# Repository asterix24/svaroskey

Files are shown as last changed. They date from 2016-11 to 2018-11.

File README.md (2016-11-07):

# svaroskey
The real and original opensource keyboard!

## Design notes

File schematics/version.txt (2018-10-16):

[petroskey]
name = "Petroskey Keyboard"
hw_ver = "0"
pcb_ver = "A"
date = "27/10/2016"

[controller]
name = "Keyboard Controller"
hw_ver = "0"
pcb_ver = "A"
date = "27/10/2016"

[controller-light]
name = "Keyboard Controller light"
hw_ver = "0"
pcb_ver = "A"
date = "04/10/2018"

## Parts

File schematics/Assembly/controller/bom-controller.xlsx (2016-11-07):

Bill of Materials
Date: Thursday, 27 October 2016 17:27:05
Project: "Keyboard Controller"
Hardware_version: "0"
PCB_version: "A"
BOM files:
- bom-controller.xls
NP=NON MONTARE!
Statistics:
52 | C Capacitors
3 | D Diodes
5 | J Connectors
9 | L Inductors, chokes
12 | Q Transistors
1 | S Mechanical parts and buttons
76 | R Resistors
9 | U IC
1 | Y Cristal, quarz, oscillator
168 | Total
T.Qty | bom-controller.xls | Designator | Comment | Footprint | Description
J Connectors
1 | 1 | J1 | Connector | usb_typeB_mini_smd | Mini USB SMT Type B 5 Contacts
1 | 1 | J3 | Connector | fcc-zif_10pin_0.5mm | Header, 10-Pin
1 | 1 | J5 | Connector | HEADER_1X3_2.54MM_THD | Header, 3-Pin
1 | 1 | J2 | Connector | HEADER_1X4_2.54MM_THD | Header, 4-Pin
1 | 1 | J4 | Connector | usb_typeB_mini_smd | Mini USB SMT Type B 5 Contacts (WE 65100516121)
S Mechanical parts and buttons
1 | 1 | BUZ1 | BUZZER | buzzer_14mm_thd
R Resistors
38 | 38 | R4, R6, R7, R10, R11, R12, R13, R14, R17, R18, R19, R20, R21, R22, R23, R24, R25, R26, R27, R28, R29, R30, R31, R32, R33, R34, R35, R36, R37, R38, R39, R40, R49, R50, R51, R52, R53, R54 | 33R | 0603_[1608] | Resistor
1 | 1 | R16 | 180R | 0603_[1608] | Resistor
1 | 1 | R15 | 680R | 0603_[1608] | Resistor
11 | 11 | R43, R47, R56, R58, R60, R62, R64, R66, R68, R70, R72 | 1k | 0603_[1608] | Resistor
1 | 1 | R45 | 1k5 | 0603_[1608] | Resistor
2 | 2 | R75, R76 | 3k3 | 0805_[2012] | Resistor
9 | 9 | R55, R57, R59, R61, R63, R65, R67, R69, R71 | 4k7 | 0603_[1608] | Resistor
5 | 5 | R2, R3, R5, R8, R9 | 10k | 0603_[1608] | Resistor
3 | 3 | R41, R73, R74 | 10k | 0603_[1608] | Resistor
1 | 1 | R44 | 33k | 0603_[1608] | Resistor
2 | 2 | R42, R48 | 47k | 0603_[1608] | Resistor
1 | 1 | R46 | 100k | 0603_[1608] | Resistor
1 | 1 | R1 | 1M | 0603_[1608] | Resistor
C Capacitors
2 | 2 | C1, C3 | 27pF | 0603_[1608] | Ceramic NP0 +/- 0.1
2 | 2 | C42, C45 | 10nF | 0603_[1608] | Ceramic X7R 50V
1 | 1 | C50 | 100nF | 0603_[1608] | CER 50V X7R
39 | 39 | C2, C7, C8, C9, C10, C13, C15, C16, C17, C18, C19, C20, C21, C22, C23, C24, C25, C26, C27, C28, C29, C30, C31, C32, C33, C34, C35, C36, C37, C38, C39, C41, C43, C46, C47, C48, C49, C51, C52 | 100nF | 0603_[1608] | Ceramic X7R 50V
1 | 1 | C4 | 1uF | 0603_[1608] | Ceramic X7R 16V
2 | 2 | C5, C6 | 2.2uF | 0603_[1608] | Ceramic 6.3V X7R
1 | 1 | C11 | 4.7uF | 0603_[1608] | Ceramic X7R 16V
1 | 1 | C40 | 4.7uF | 1206_[3216] | Ceramic X7R 16V
1 | 1 | C44 | 4.7uF | 1206_[3216] | Ceramic X5R 25V
2 | 2 | C12, C14 | 10uF | 1206_[3216] | Ceramic X5R 25V
D Diodes
2 | 2 | D1, D2 | LED | 0603_[1608]_K2-A1_LED | LED Green
1 | 1 | D3 | MBR120VLSFT1G | SOD-123 | Diode Schottky low Vf, If 1A (PMEG3010ER; MBRX120LF)
L Inductors, chokes
8 | 8 | L2, L3, L4, L5, L6, L7, L8, L9 | 220H ohm @ 100MHz | 0805_[2012] | WE 742792022
1 | 1 | L1 | 220H ohm @ 100MHz | 0805_[2012] | Inductor
Q Transistors
3 | 3 | Q1, Q2, Q3 | BC817 | SOT-23 | BJT NPN
1 | 1 | Q4 | MOSFET P | SOT-23 | IRLML5103TRPbF; DMG1013UW;
8 | 8 | Q5, Q6, Q7, Q8, Q9, Q10, Q11, Q12 | MOSFET P | SOT-23
Y Cristal, quarz, oscillator
1 | 1 | Y1 | 8MHz | CRYSTAL_3.2X2.5MM_4P_SMD
U IC
1 | 1 | U1 | 24C128 | SOIC8 | EEPROM
1 | 1 | U6 | FT232RQ | QFN-32 | Serial TTL 232 <-> USB (QFN-32)
1 | 1 | U3 | LM1117xxx-3.3 | SOT-223 | LM1117 LDO Fixed output
2 | 2 | U8, U9 | Led Driver | TSOP65P640X120_HS-25N | (Texas TLC5928; ST STP16CP05)
1 | 1 | U7 | MC74HC595AD | SOIC16 | 8-Bit Serial-Input/Serial or Prallel-Output Shift Register with Latched 3-State Outputs
1 | 1 | U2 | STM32F103RB | TSQFP50P1200X1200X160-64N | STM32F103RB
2 | 2 | U4, U5 | TVS Array (WE 82400152) | SOT-563 | TVS Array (WE 82400152)

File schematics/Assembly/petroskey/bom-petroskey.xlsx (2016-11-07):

Bill of Materials
Date: Thursday, 27 October 2016 17:27:05
Project: "Petroskey Keyboard"
Hardware_version: "0"
PCB_version: "A"
BOM files:
- bom-petroskey.xls
NP=NON MONTARE!
Statistics:
52 | C Capacitors
139 | D Diodes
4 | J Connectors
9 | L Inductors, chokes
12 | Q Transistors
66 | S Mechanical parts and buttons
76 | R Resistors
9 | U IC
1 | Y Cristal, quarz, oscillator
368 | Total
T.Qty | bom-petroskey.xls | Designator | Comment | Footprint | Description
J Connectors
1 | 1 | J5 | Connector | fcc-zif_10pin_0.5mm
1 | 1 | J3 | Connector | usb_typeB_mini_smd | Mini USB SMT Type B 5 Contacts (WE 65100516121)
1 | 1 | J4 | Connector | HEADER_1X6_2.54MM_THD | Pin Header, 1x6, 2.54mm.
1 | 1 | J1 | Connector | usb_typeB_mini_smd | Mini USB SMT Type B 5 Contacts
S Mechanical parts and buttons
1 | 1 | BUZ1 | BUZZER | buzzer_14mm_thd
65 | 65 | K1, K2, K3, K4, K5, K6, K7, K8, K9, K10, K11, K12, K13, K14, K15, K16, K17, K18, K19, K20, K21, K22, K23, K24, K25, K26, K27, K28, K29, K30, K31, K32, K33, K34, K35, K36, K37, K38, K39, K40, K41, K42, K43, K44, K45, K46, K47, K48, K49, K50, K51, K52, K53, K54, K55, K56, K57, K58, K59, K60, K61, K62, K63, K64, K65 | KEY0 | tactile_switch_gateron_pcb | Tactile Switch Right Angle 6x6
R Resistors
40 | 40 | R12, R13, R16, R17, R18, R19, R20, R21, R25, R27, R30, R31, R32, R33, R36, R37, R38, R39, R40, R41, R42, R43, R44, R45, R46, R47, R48, R49, R50, R51, R52, R53, R54, R55, R56, R57, R58, R59, R76, R77 | 33R | 0603_[1608] | Resistor
1 | 1 | R35 | 180R | 0603_[1608] | Resistor
1 | 1 | R34 | 680R | 0603_[1608] | Resistor
11 | 11 | R5, R61, R63, R65, R67, R69, R71, R73, R75, R80, R82 | 1k | 0603_[1608] | Resistor
1 | 1 | R7 | 1k5 | 0603_[1608] | Resistor
2 | 2 | R78, R79 | 3k3 | 0805_[2012] | Resistor
9 | 9 | R60, R62, R64, R66, R68, R70, R72, R74, R83 | 4k7 | 0603_[1608] | Resistor
5 | 5 | R23, R24, R26, R28, R29 | 10k | 0603_[1608] | Resistor
1 | 1 | R1 | 10k | 0603_[1608] | Resistor
1 | 1 | R6 | 33k | 0603_[1608] | Resistor
2 | 2 | R2, R81 | 47k | 0603_[1608] | Resistor
1 | 1 | R8 | 100k | 0603_[1608] | Resistor
1 | 1 | R22 | 1M | 0603_[1608] | Resistor
C Capacitors
2 | 2 | C11, C13 | 27pF | 0603_[1608] | Ceramic NP0 +/- 0.1
2 | 2 | C3, C7 | 10nF | 0603_[1608] | Ceramic X7R 50V
1 | 1 | C50 | 100nF | 0603_[1608] | CER 50V X7R
39 | 39 | C2, C4, C5, C8, C9, C10, C12, C17, C18, C19, C20, C23, C25, C26, C27, C28, C29, C30, C31, C32, C33, C34, C35, C36, C37, C38, C39, C40, C41, C42, C43, C44, C45, C46, C47, C48, C49, C51, C52 | 100nF | 0603_[1608] | Ceramic X7R 50V
1 | 1 | C14 | 1uF | 0603_[1608] | Ceramic X7R 16V
2 | 2 | C15, C16 | 2.2uF | 0603_[1608] | Ceramic 6.3V X7R
1 | 1 | C21 | 4.7uF | 0603_[1608] | Ceramic X7R 16V
1 | 1 | C1 | 4.7uF | 1206_[3216] | Ceramic X7R 16V
1 | 1 | C6 | 4.7uF | 1206_[3216] | Ceramic X5R 25V
2 | 2 | C22, C24 | 10uF | 1206_[3216] | Ceramic X5R 25V
D Diodes
35 | 35 | D156, D157, D158, D159, D165, D166, D167, D168, D173, D174, D175, D176, D181, D182, D183, D184, D189, D190, D191, D192, D197, D198, D199, D201, D206, D207, D208, D209, D212, D213, D214, D215, D216, D217, D218 | LED | R3_RGB_LED_THD | Led RGB Thrue Hole
2 | 2 | D2, D3 | LED | 0603_[1608]_K2-A1_LED | LED Green
1 | 1 | D1 | MBR120VLSFT1G | SOD-123 | Diode Schottky low Vf, If 1A (PMEG3010ER; MBRX120LF)
30 | 30 | D148, D152, D154, D155, D160, D161, D162, D163, D169, D170, D171, D172, D177, D178, D179, D180, D185, D186, D187, D188, D193, D194, D195, D196, D202, D203, D204, D205, D210, D211 | RBG |  | Led RGB Thrue Hole
6 | 6 | D149, D150, D151, D153, D164, D200 | RBG | led_3.2x2.8mm_4p_smd | Led RGB Thrue Hole
65 | 65 | D4, D5, D6, D7, D8, D9, D10, D11, D12, D13, D14, D15, D16, D17, D18, D19, D20, D21, D22, D23, D24, D25, D26, D27, D28, D29, D30, D31, D32, D33, D34, D35, D36, D37, D38, D39, D40, D41, D42, D43, D44, D45, D46, D47, D48, D49, D50, D51, D52, D53, D54, D55, D56, D57, D58, D59, D60, D61, D62, D63, D64, D65, D66, D67, D68 | diode | SOD-123 | Diode Schottky low Vf, If 1A (PMEG3010ER; MBRX120LF)
L Inductors, chokes
8 | 8 | L1, L2, L3, L4, L5, L6, L7, L9 | 220H ohm @ 100MHz | 0805_[2012] | WE 742792022
1 | 1 | L8 | 220H ohm @ 100MHz | 0805_[2012] | Inductor
Q Transistors
3 | 3 | Q1, Q2, Q11 | BC817 | SOT-23 | BJT NPN
1 | 1 | Q3 | MOSFET P | SOT-23 | IRLML5103TRPbF; DMG1013UW;
8 | 8 | Q4, Q5, Q6, Q7, Q8, Q9, Q10, Q12 | MOSFET P | SOT-23
Y Cristal, quarz, oscillator
1 | 1 | Y1 | 8MHz | CRYSTAL_3.2X2.5MM_4P_SMD
U IC
1 | 1 | U4 | 24C128 | SOIC8 | EEPROM
1 | 1 | U3 | FT232RQ | QFN-32 | Serial TTL 232 <-> USB (QFN-32)
1 | 1 | U6 | LM1117xxx-3.3 | SOT-223 | LM1117 LDO Fixed output
2 | 2 | U8, U9 | Led Driver | TSOP65P640X120_HS-25N | (Texas TLC5928; ST STP16CP05)
1 | 1 | U7 | MC74HC595AD | SOIC16 | 8-Bit Serial-Input/Serial or Prallel-Output Shift Register with Latched 3-State Outputs
1 | 1 | U5 | STM32F103RB | TSQFP50P1200X1200X160-64N | STM32F103RB
2 | 2 | U1, U2 | TVS Array (WE 82400152) | SOT-563 | TVS Array (WE 82400152)

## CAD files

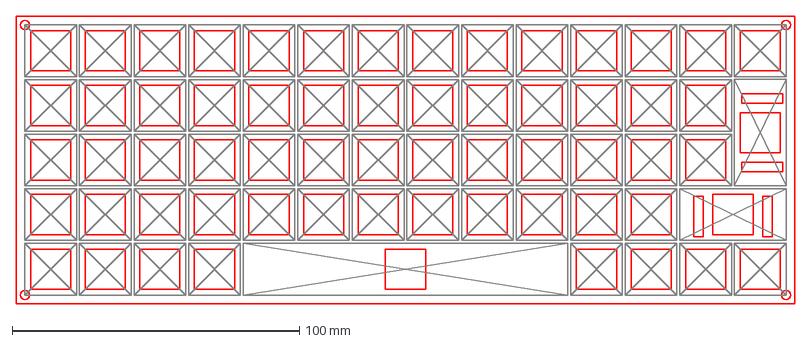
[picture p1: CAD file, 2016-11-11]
schematics/Drawing/pietroskey_layout.dxf
271.0 x 100.0 mm

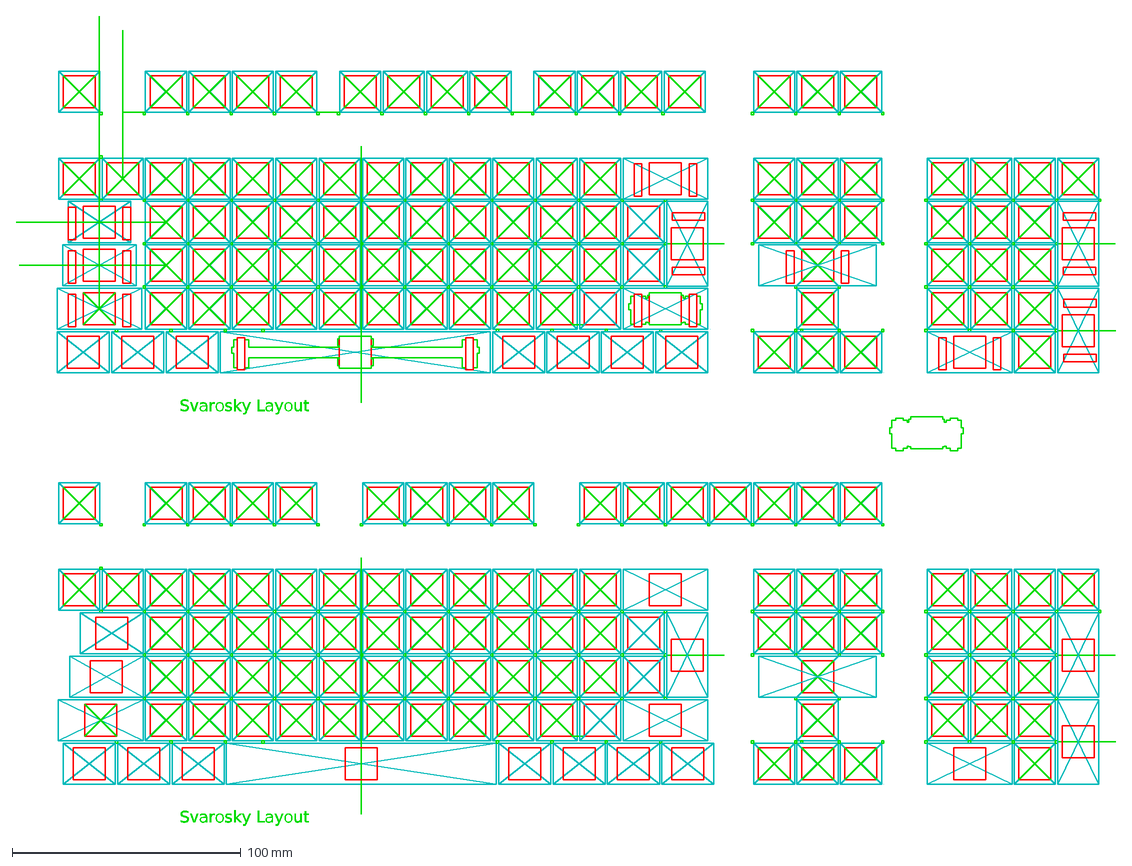
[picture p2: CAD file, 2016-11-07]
schematics/Drawing/svarosky_layout.dxf
Svarosky Layout

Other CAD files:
schematics/Drawing/asterix-print.dxf
schematics/Drawing/asterix_layout_variante.dxf
schematics/Drawing/asterix_layout.dxf
schematics/Drawing/disegno_tastiera.dxf
schematics/Drawing/asterix_layout_variante.dwg

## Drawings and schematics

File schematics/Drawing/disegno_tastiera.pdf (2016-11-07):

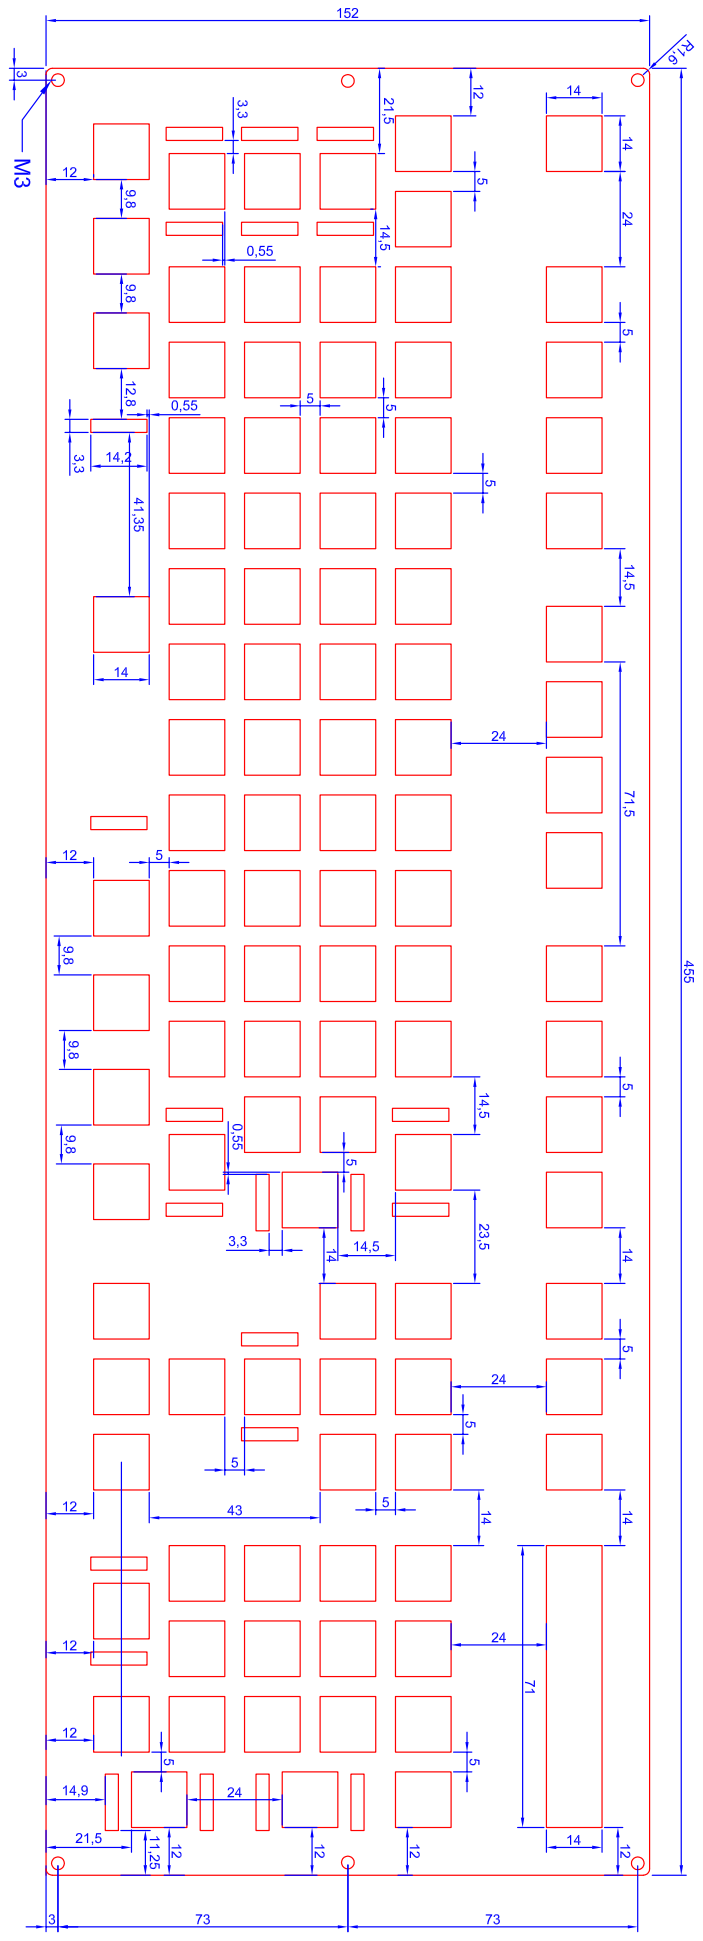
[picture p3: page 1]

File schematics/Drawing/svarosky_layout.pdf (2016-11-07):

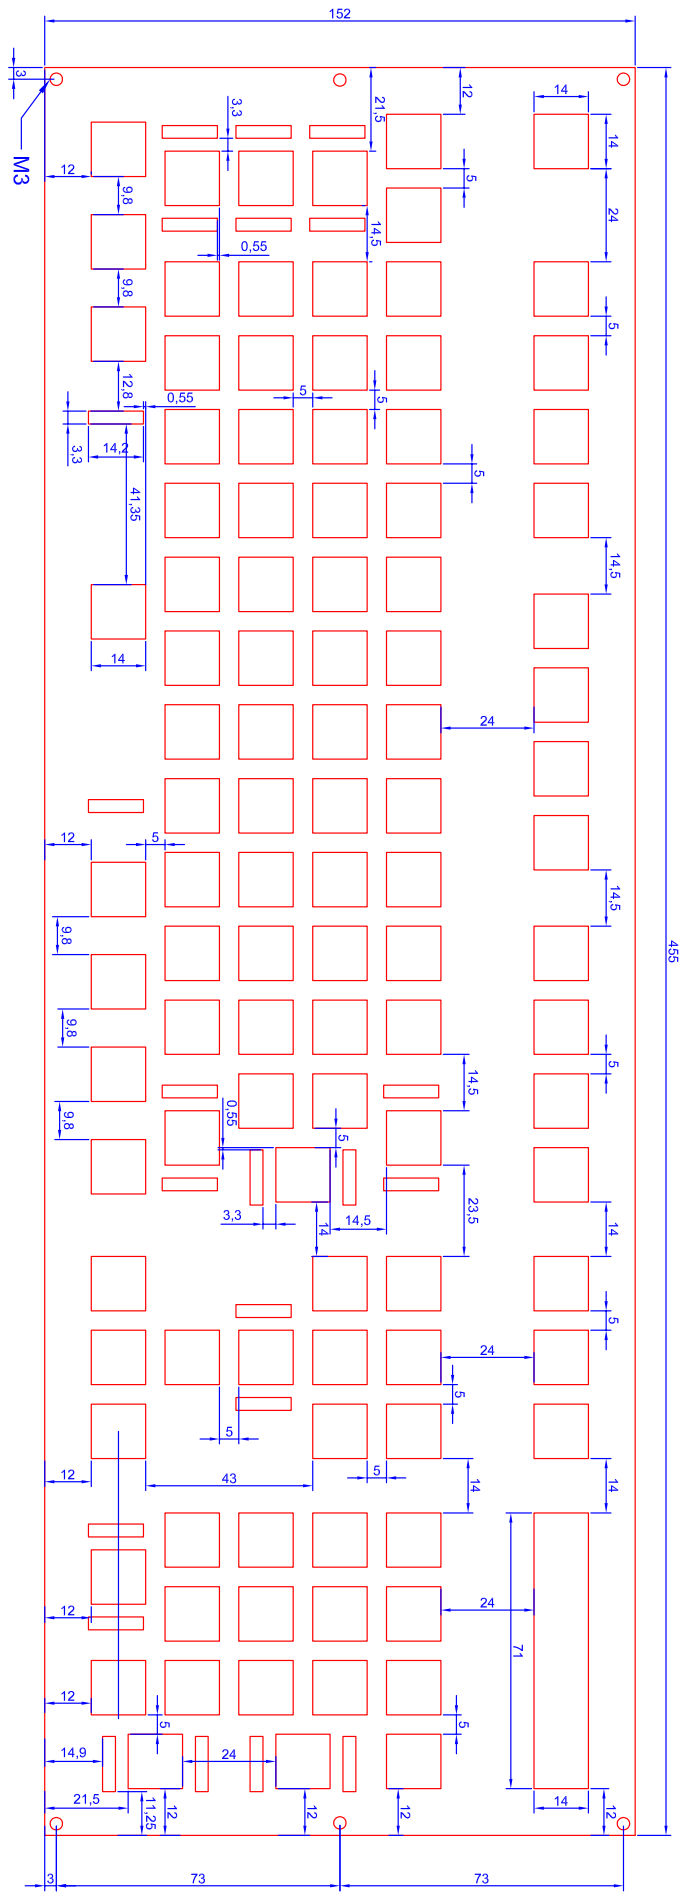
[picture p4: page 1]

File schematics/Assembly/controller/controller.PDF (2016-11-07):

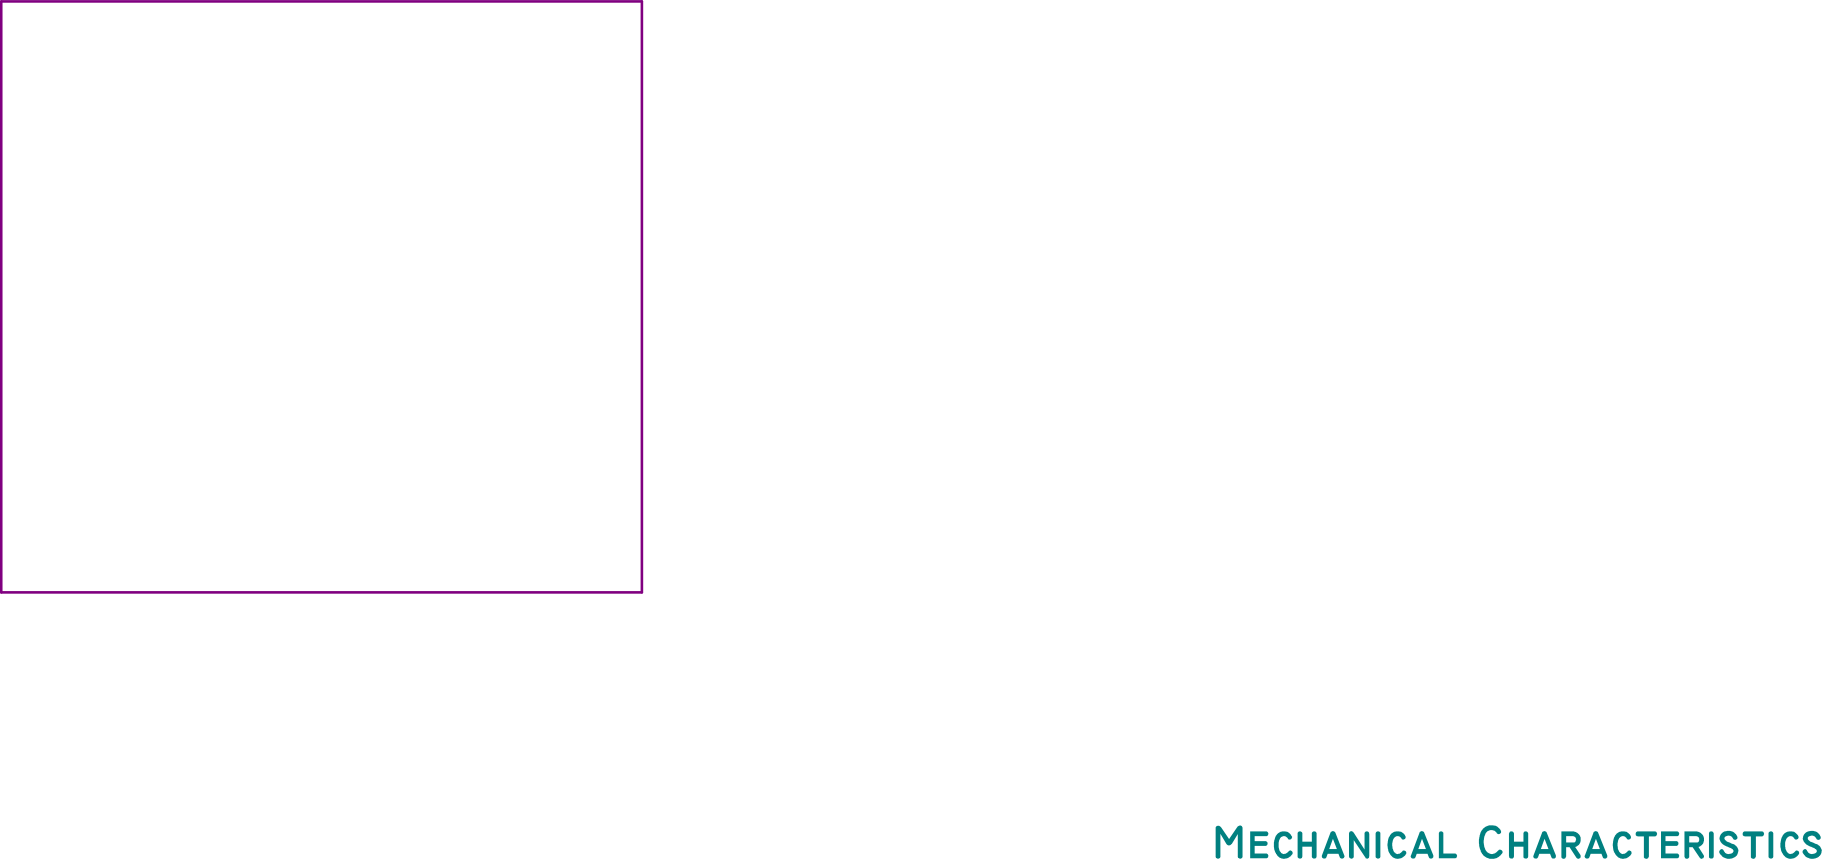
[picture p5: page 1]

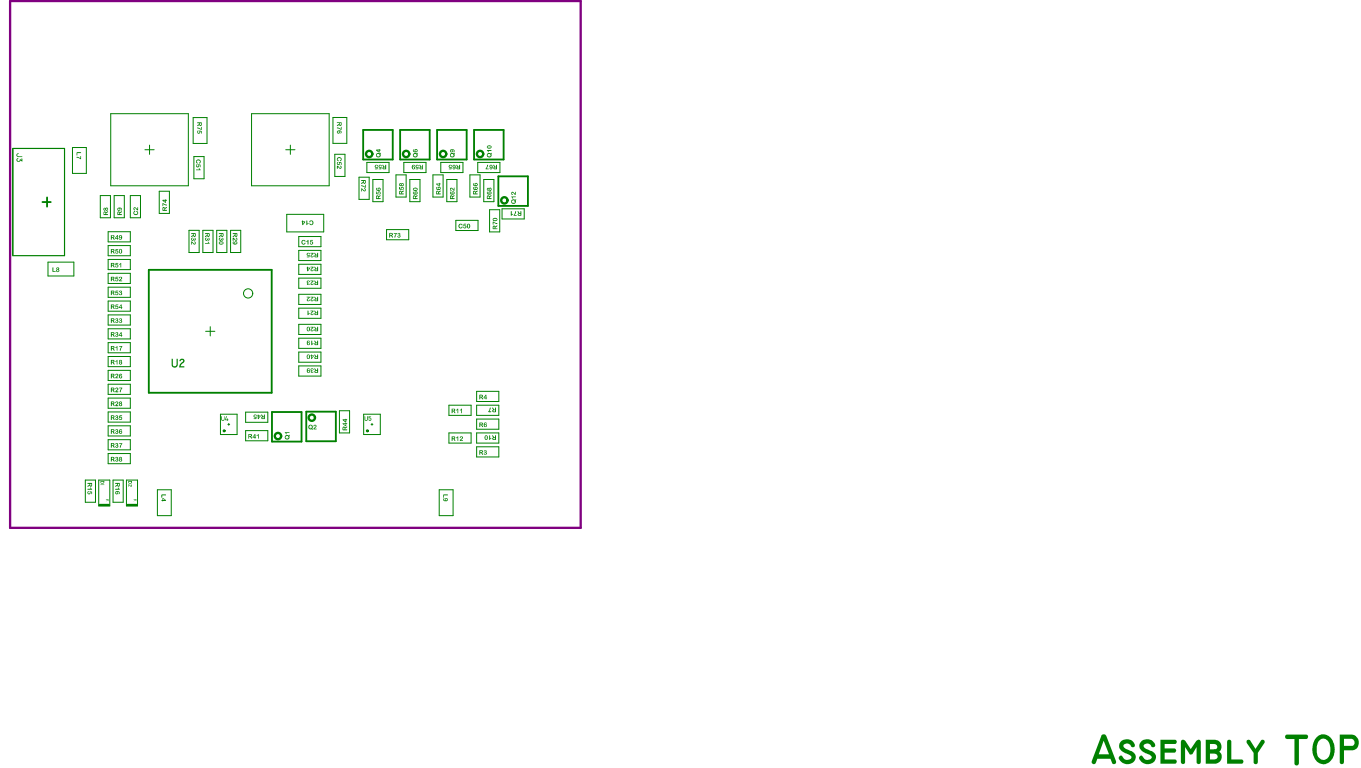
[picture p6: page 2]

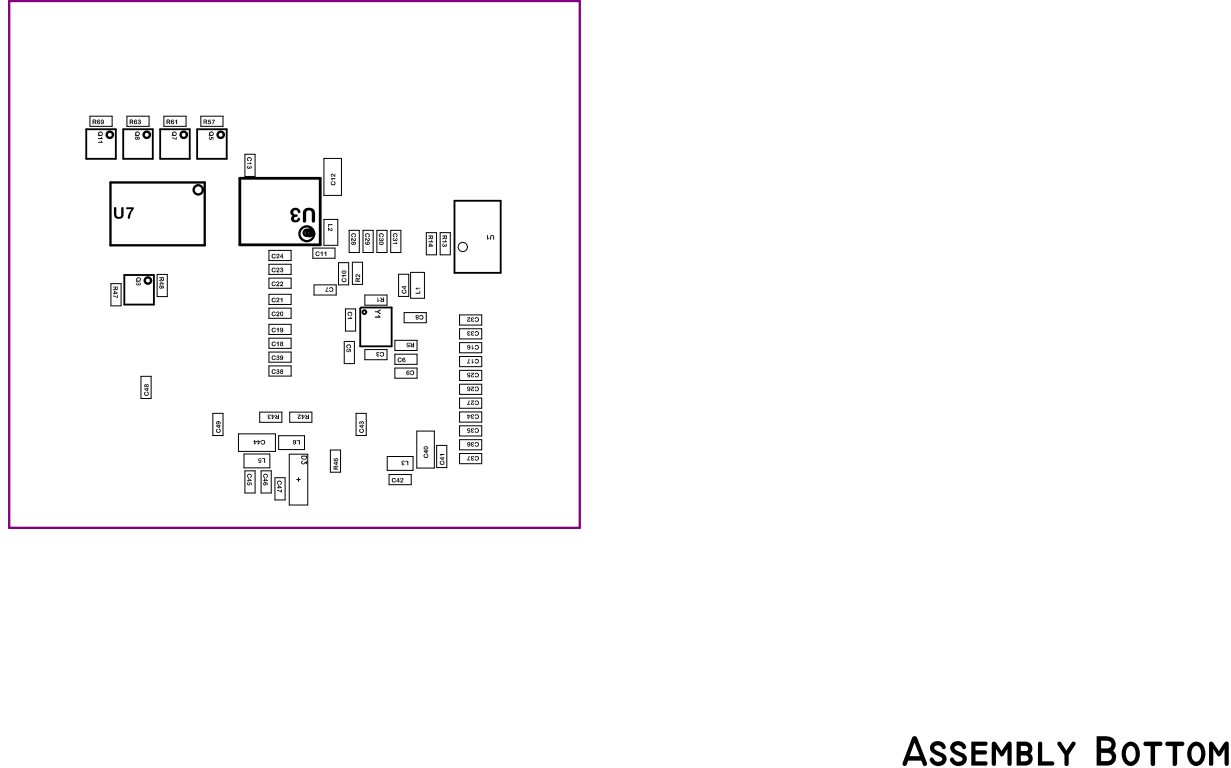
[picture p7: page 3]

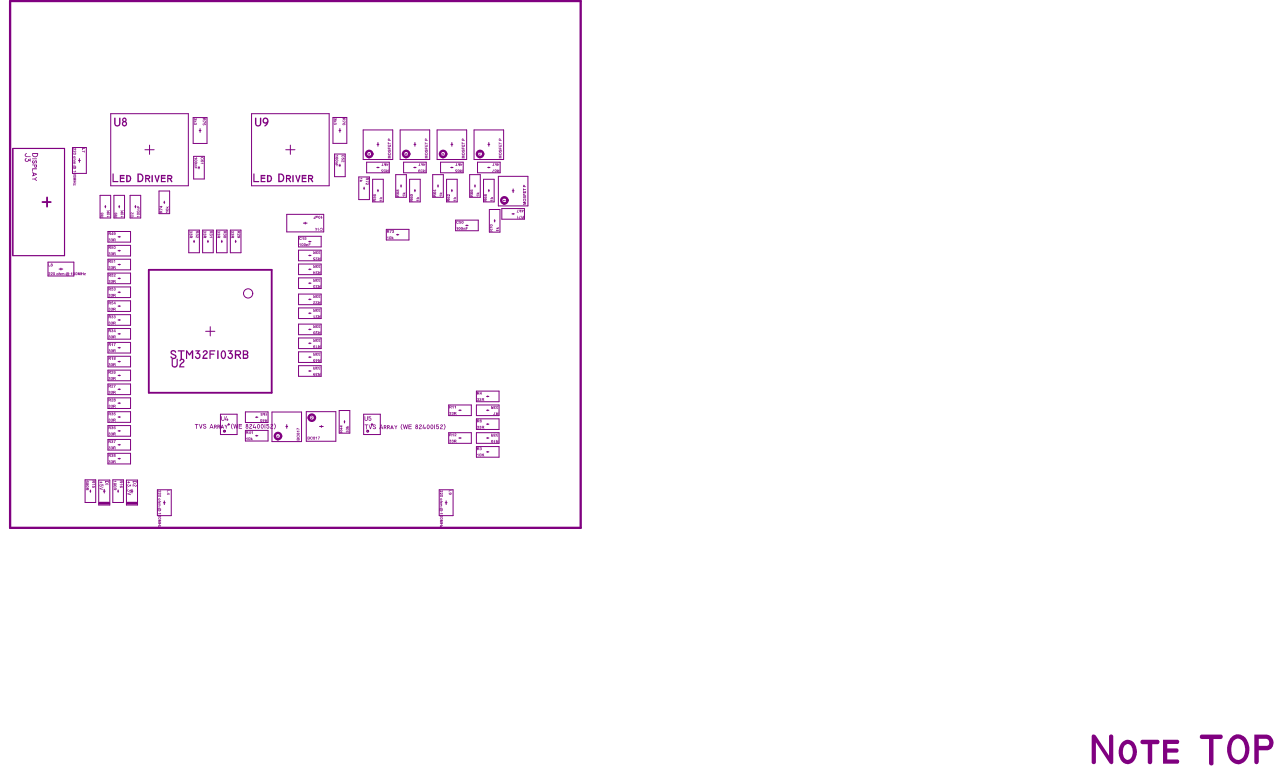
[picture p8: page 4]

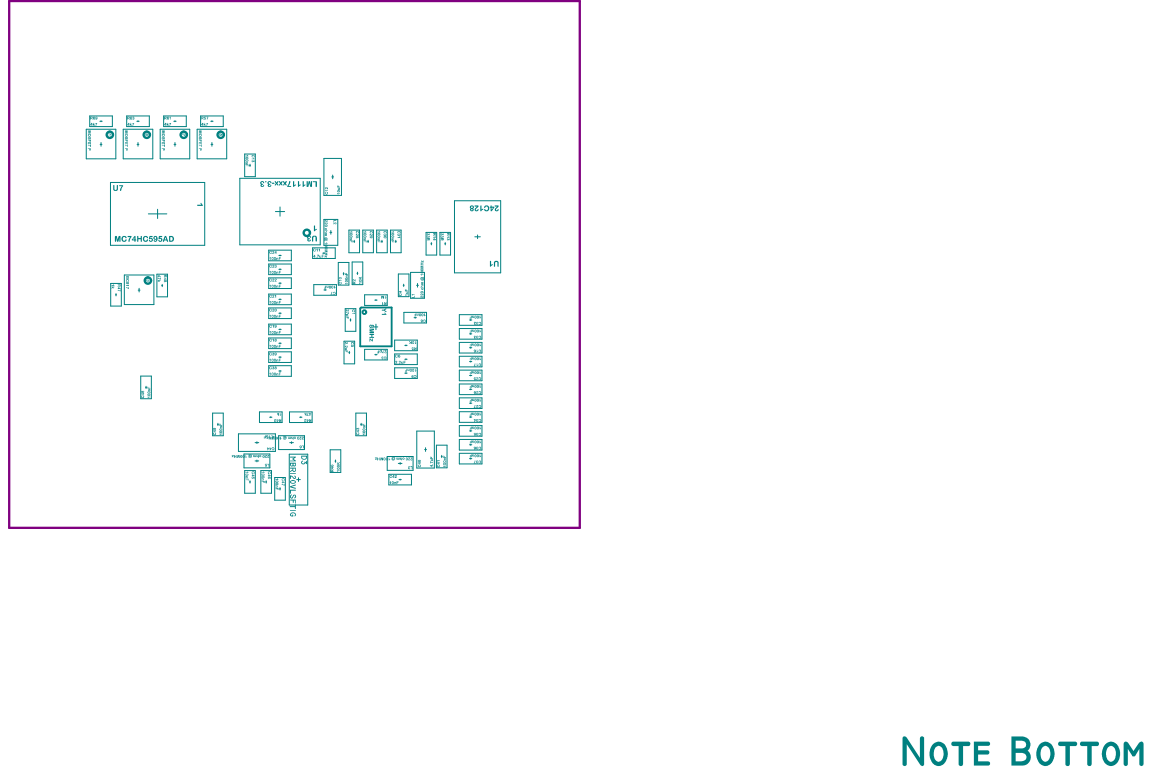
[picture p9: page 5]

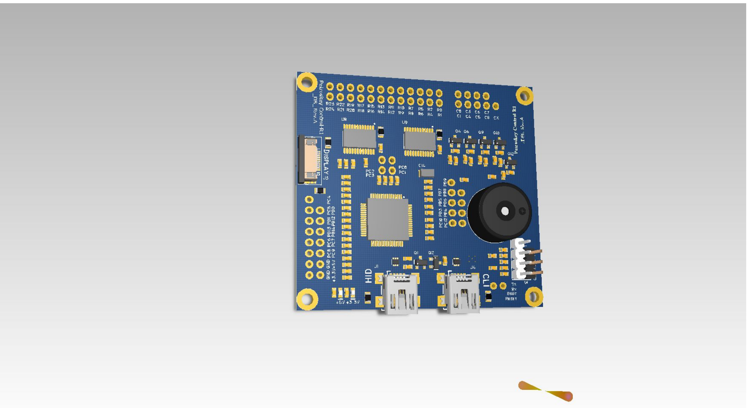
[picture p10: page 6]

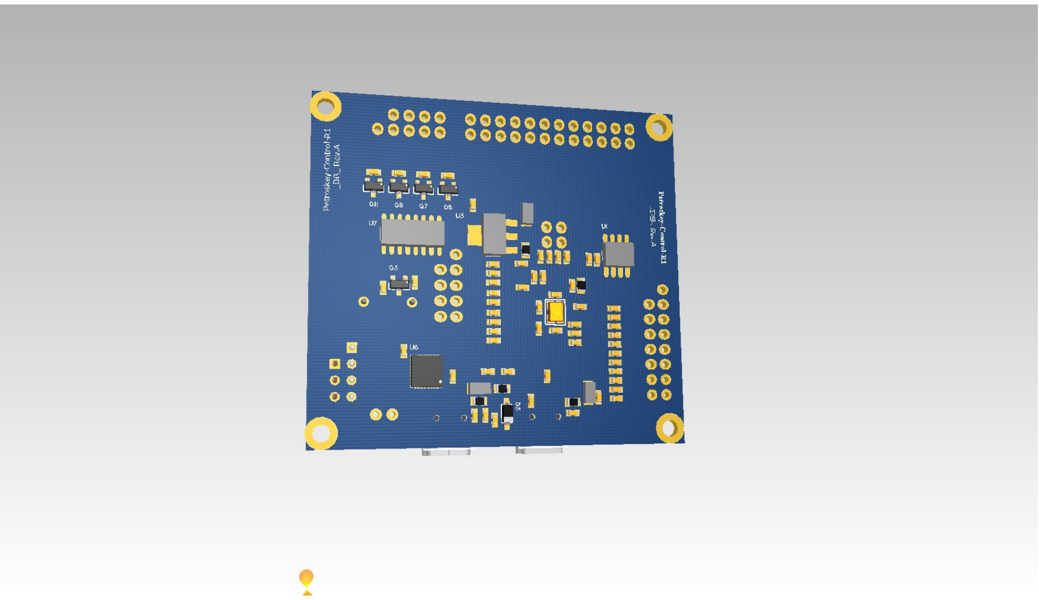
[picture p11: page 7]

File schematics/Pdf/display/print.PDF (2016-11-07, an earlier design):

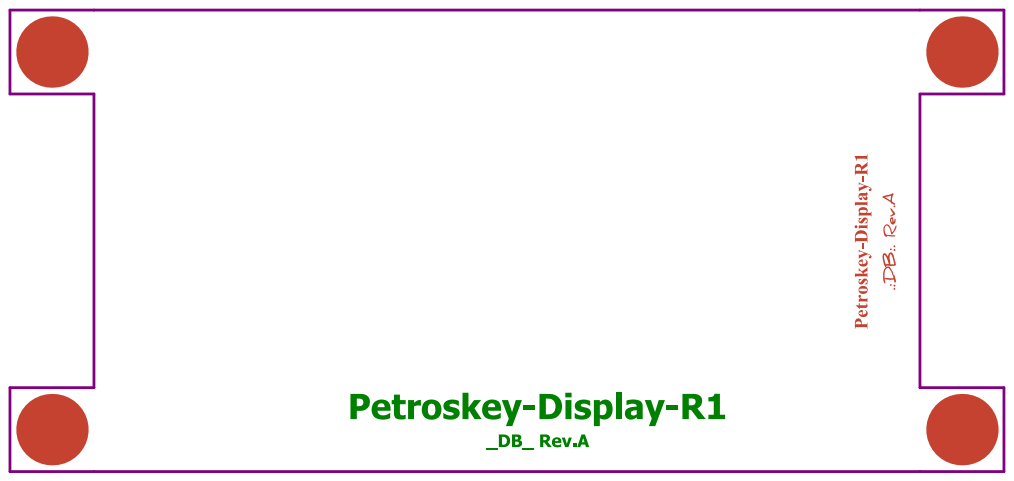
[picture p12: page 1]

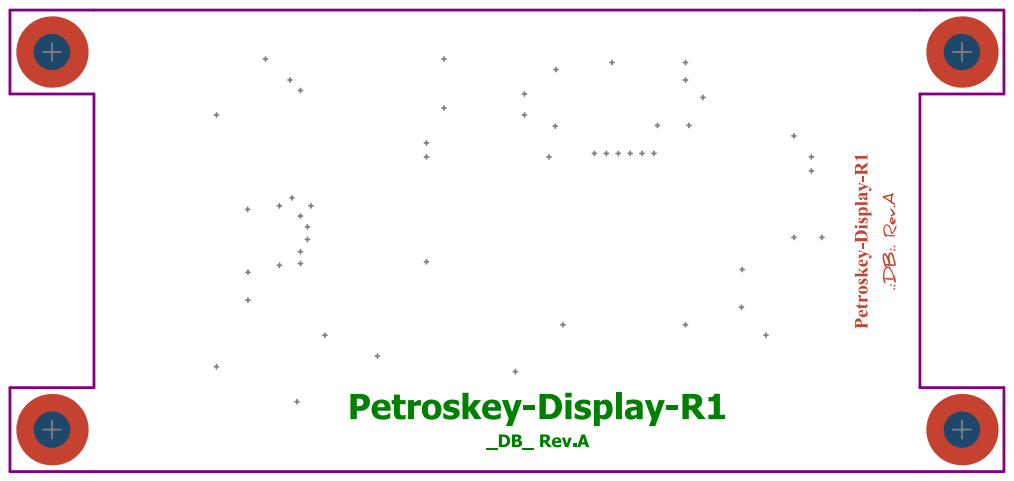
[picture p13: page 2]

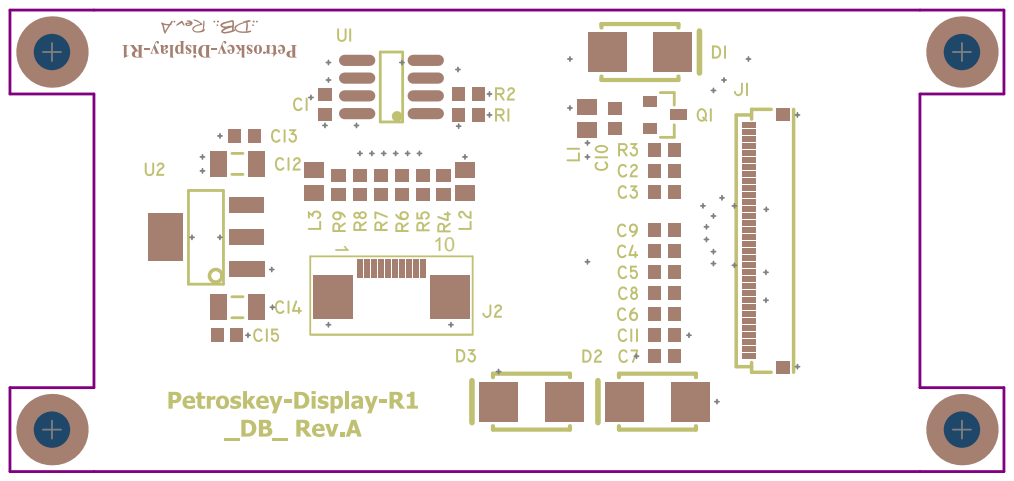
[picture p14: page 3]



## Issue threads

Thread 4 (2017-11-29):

Tastiera non si spegne & non va in grub

Svalorzen, 2017-11-29:
Ciao ragazzuoli, so che ormai il supporto per la tastiera è parziale, ma volevo mettervi al corrente di come va adesso perchè l'ho finalmente rimontata al pc.

L'ho attaccata ad una presa USB sul retro del pc, dove ci ho messo tranquillamente anche un mouse. Se il PC è spento, il mouse si spegne, ma la tastiera no. Quindi non so cosa c'abbia dentro che persiste nel succhiare e rimanere viva. Questo vuol dire che ancora una volta c'è il problema che va staccata e riattaccata per farla funzionare.

In aggiunta sul mio PC a casa ho dual boot con Windows che usa grub. La tastiera NON va in grub, quindi non posso usarla per selezionare la entry iniziale. Una volta che ubuntu boota poi funziona di nuovo. No idea del perchè. Questo è indipendente dal fatto che la tastiera si fosse piantata perchè non era stata spenta o no.

Fatemi sapere quando avete tempo (o anche solo se leggete questo ticket) =).

Ciao!

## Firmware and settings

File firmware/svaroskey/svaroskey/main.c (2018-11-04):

/**
 * \file
 * <!--
 * This file is part of BeRTOS.
 *
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
 * As a special exception, you may use this file as part of a free software
 * library without restriction.  Specifically, if other files instantiate
 * templates or use macros or inline functions from this file, or you compile
 * this file and link it with other files to produce an executable, this
 * file does not by itself cause the resulting executable to be covered by
 * the GNU General Public License.  This exception does not however
 * invalidate any other reasons why the executable file might be covered by
 * the GNU General Public License.
 *
 * Copyright 2010 Develer S.r.l. (http://www.develer.com/)
 *
 * -->
 *
 * \author Andrea Righi <arighi@develer.com>
 *
 * \brief BeRTOS virtual keyboard.
 *
 * This project implements a HID USB device using the Olimex STM32-P103
 * evaluation board. The virtual keyboard can be connected to the USB port of a
 * normal PC.
 *
 * The WAKE_UP button on the board can be pressed to send to the host the
 * keyboard scancodes that simulate the typing of http://www.bertos.org.
 *
 * NOTE: this only works if the keyboard layout on the host PC is set to "US"
 * (QWERTY).
 *
 * Example (keyboard detection on Linux):
 *
 * \verbatim
 * [24388.400573] usb 1-8.1.3: new full speed USB device using ehci_hcd and address 32
 * [24388.623957] usb 1-8.1.3: configuration #1 chosen from 1 choice
 * [24388.685827] input: BeRTOS USB Keyboard as /devices/pci0000:00/0000:00:1d.7/usb1/1-8/1-8.1/1-8.1.3/1-8.1.3:1.0/input/input18
 * [24388.688953] generic-usb 0003:FFFF:0000.0007: input,hidraw3: USB HID v1.10 Keyboard [BeRTOS USB Keyboard] on usb-0000:00:1d.7-8.1.3/input0
 * \endverbatim
 *
 */

#include "keyboard.h"
#include "layouts.h"

#include "hw/hw_boot.h"


#include <cfg/debug.h>
#define LOG_LEVEL  2
#define LOG_FORMAT 0

#include <cfg/log.h>

#include <common/usbfeature.h>

#include <cpu/irq.h>
#include <cpu/power.h>

#include <drv/sipo.h>
#include <drv/timer.h>
#include <drv/usbkbd.h>
#include <drv/usbser.h>
#include <drv/eeprom.h>
#include <drv/flash.h>

#include <io/kfile_block.h>
#include <struct/list.h>
#include <kern/proc.h>
#include <mware/event.h>

#define MAX_BRIGHTNESS 100
#define NUM_LED_ROWS   8
#define NUM_LED_COLS   8
#define NUM_LEDS       (NUM_LED_COLS * NUM_LED_ROWS)

static Sipo sipo;
static Eeprom eep;
static I2c i2c;
static Flash internal_flash;
static KFileBlock flash;

static Event key_status_change;

static UsbFeatureCtx usb_feature_ctx;
static UsbFeatureMsg usb_feature_msg;

static uint8_t leds_off[3]  = {0x00, 0x00, 0x00};

static void hw_init(void)
{
	reg32_t *AFIO;

	/* Disable JTAG function on PB3 and use it as GPIO */
	RCC->APB2ENR |= RCC_APB2_AFIO;
	AFIO = (reg32_t *)(AFIO_BASE + 4);
	*AFIO &= ~(0x07000000);
	*AFIO |=  (0x04000000);
}

static void init(void)
{
	/* Initialize low-level platform */
	hw_init();

	/* Enable all the interrupts */
	IRQ_ENABLE;

	/* Initialize debugging module (allow kprintf(), etc.) */
	kdbg_init();

	kprintf("\n\n==== Main HID App ====\n");


	hw_keymap_init();

	/* Initialize system timer */
	timer_init();

	/* Kernel initialization */
	proc_init();

	/* Initialize SIPO */
	sipo_init(&sipo, 0, SIPO_DATAORDER_LSB);
	kfile_write(&sipo.fd, leds_off, sizeof(leds_off));

	flash_init(&internal_flash, FLASH_WRITE_ONCE);
	// trim flash to avoid problems with kfile_block
	LOG_INFO("Trim start: %d, blocks: %ld\n", TRIM_START, internal_flash.blk.blk_cnt - TRIM_START);
	kblock_trim(&internal_flash.blk, TRIM_START, internal_flash.blk.blk_cnt - TRIM_START);
	kfileblock_init(&flash, &internal_flash.blk);

	/* init usb feature to run custom cmd. */
	usbfeature_init(&usb_feature_ctx, &usb_feature_msg, &flash.fd);
	usbfeature_setStatus(&usb_feature_ctx, FEAT_ST_APP);

	///* Initialize the USB keyboard device */
	usbkbd_eventRegister(); // For custom feature
	usbkbd_init(0);

	/* Initialize keymap */
	hw_keymap_init();

	/* Initialize EEPROM */
	i2c_init(&i2c, I2C_BITBANG0, CONFIG_I2C_FREQ);
	eeprom_init(&eep, &i2c, EEPROM_24XX128, 0x00, false);

	layout_init();

}

static void NORETURN feature_proc(void)
{
	/* Wait feature command from usb */
	while (1)
	{
		usbfeature_poll(&usb_feature_ctx);
	}
}

static KeyScanCtx keymap_status;

static void NORETURN scan_proc(void)
{
	/* Periodically scan the keyboard */
	while (1)
	{
		ticks_t start = timer_clock();
		while ((timer_clock() - start) < ms_to_ticks(10))
		{
			hw_keymap_scan(&keymap_status);
			timer_delay(1);
		}

		for (int i = 0; i < MAX_KEY_STATUS; i++)
		{
			if (keymap_status.status[i] & KEY_CHANGED)
			{
				event_do(&key_status_change);
				break;
			}
		}
		cpu_relax();
	}
}

static void dump(const char* label)
{
	kprintf("%s: [", label);
	for (int i = 0; i < MAX_KEY_STATUS; i++)
		kprintf("%d {%x}, ", keymap_status.index[i], keymap_status.status[i]);
	kputs("]\n");
}

int main(void)
{
	/* Hardware initialization */
	init();

	/* Sample process */

	event_initGeneric(&key_status_change);

	proc_new(scan_proc, NULL, KERN_MINSTACKSIZE, NULL);
	proc_new(feature_proc, NULL, 0x400, NULL);

	while (1)
	{
		UsbKbdEvent event;
		memset(&event, 0x0, sizeof(UsbKbdEvent));

		// Wait key press status changes
		event_wait(&key_status_change);
		dump("Scanned");

		if (layout_usbEvent(&event, &keymap_status) < 0)
		{
			LOG_ERR("Layout event error\n");
			continue;
		}

		usbkbd_sendEvent(&event);
		dump("Process");
		 kputs("\n...................\n");
	}
	return 0;
}

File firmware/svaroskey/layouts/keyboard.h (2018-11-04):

/**
 * \file
 * <!--
 * Copyright 2018 Daniele Basile <asterix24@gmail.com>
 * All Rights Reserved.
 * -->
 *
 * \brief 
 *
 * \author Daniele Basile <asterix24@gmail.com>
 */


#ifndef LAYOUT_KEYBOARD_H
#define LAYOUT_KEYBOARD_H

#include "cfg/cfg_keymap.h"

#include <cpu/types.h>

#define KEY_PORTA 0
#define KEY_PORTB 1
#define KEY_PORTC 2

typedef struct {
	uint8_t col;
	uint8_t col_port_idx;
	uint8_t row;
	uint8_t row_port_idx;
} KeyMap;


#define MAX_KEY_STATUS 10

typedef struct {
	uint8_t index[MAX_KEY_STATUS];
	uint8_t status[MAX_KEY_STATUS];
} KeyScanCtx;

/*
 * Define column and rows for matrix keys.
 * Column should be place to power supply, and row to ground.
 */

#if CFG_KEYBOARD_LAYOUT == KEYBOARD_PETROSKEY_LAYOUT
	#include "hw/petroskey.h"
#else
	#error No layout defined
#endif

#define KEY_RELEASE       0
#define KEY_PRESSED       BV(0)
#define KEY_CHANGED       BV(7)


extern KeyMap keyboard_layout[KEYBOARD_LAYOUT_NUM_KEYS];

bool hw_keymap_read(uint8_t index);
void hw_keymap_scan(KeyScanCtx *ctx);
int hw_keymap_popKey(KeyScanCtx *ctx, uint8_t index);
void hw_keymap_pushKey(KeyScanCtx *ctx, uint8_t index, uint8_t status);

void hw_keymap_init(void);

#endif /* LAYOUT_KEYBOARD_H */

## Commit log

2016-11-07 Add project for keyboard controller.
    [keyboard.PrjPcb]
2016-11-07 Add first cpu scheme.
    [cpu.SchDoc]
2016-11-07 Add drawing for keyboard layout.
    [svarosky_layout.dxf]
2016-11-07 Add usb connector and init circuit. Add eeprom for data storage. Draw power supplay.
    [cpu.SchDoc]
2016-11-07 Connect swd wire.
    [cpu.SchDoc]
2016-11-07 Add power led.
    [cpu.SchDoc]
2016-11-07 Add scheme for keymap.
    [keymap.SchDoc]
2016-11-07 Add testpoint for each row/col.
    [keymap.SchDoc]
2016-11-07 Add pcb template.
    [cpu.SchDoc, keyboard.PrjPcb, svarosky_layout.dxf]
2016-11-07 Assign all footprint, except cherry-mx keys.
    [cpu.SchDoc, keyboard.PrjPcb, keymap.SchDoc]
2016-11-07 Move all scheme in separate folder.
    [cpu.SchDoc, keyboard.PcbDoc, keyboard.PrjPcb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]
2016-11-07 Update files.
    [cpu.SchDoc, disegno_tastiera.dxf, keyboard.PcbDoc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]
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2016-11-07 Add missing hw_clean support for stm32f1, probably forget during stm32f2 poting.
2016-11-07 Add sipo driver for leds.
    [cpu.SchDoc, keyboard.PrjPcb, keymap.SchDoc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]
2016-11-07 Update output file with leds scheme.
    [cpu.SchDoc, keyboard.PrjPcb, led_driver.SchDoc]
2016-11-07 Reorder project.
    [cpu.SchDoc, keyboard.PcbDoc, keyboard.PrjPcb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]
2016-11-07 Rename prj files.
    [controller.PcbDoc, controller.PrjPcb]
2016-11-07 Add prj for petroskey.
    [connectors.SchDoc, cpu.SchDoc, keymap.SchDoc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]
2016-11-07 Add pcb prj for display.
    [connectors.SchDoc, display.PrjPcb]
2016-11-07 Draw keymap. Add connector layout scheme.
    [connectors.SchDoc, cpu.SchDoc, keymap.SchDoc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]
2016-11-07 Add ftdi. Complete scheme. Annotate.
    [connectors.SchDoc, cpu.SchDoc, keymap.SchDoc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]
2016-11-07 Fix keymap. Annotate scheme. Assign all footprints.
    [connectors.SchDoc, cpu.SchDoc, keymap.SchDoc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]
2016-11-07 Add settings to prj, generate assembly pdf.
    [petroskey.PrjPcb]
2016-11-07 Place all switches. Start to place all components.
    [petroskey.PcbDoc]
2016-11-07 Continue placing.
    [connectors.SchDoc, cpu.SchDoc, keymap.SchDoc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]
2016-11-07 Re-draw led circuit, using specific led driver and mos-p channel. Now we have 8 column for 24 row.
    [led.SchDoc, led_driver.SchDoc]
2016-11-07 Complete led circuit. Place thd leds.
    [connectors.SchDoc, cpu.SchDoc, keymap.SchDoc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]
2016-11-07 Use smd footprint for some leds.
    [led.SchDoc, petroskey.PrjPcb]
2016-11-07 Start routing.
    [connectors.SchDoc, led.SchDoc, petroskey.PrjPcb]
2016-11-07 Reorder led placing. Continue routing.
    [connectors.SchDoc, cpu.SchDoc, keymap.SchDoc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]
2016-11-07 Continue routing.
    [cpu.SchDoc, led.SchDoc]
2016-11-07 Add frame shield signal. Start to route cpu.
    [connectors.SchDoc]
2016-11-07 Continue roting. Spit drawing fro two type of keyboard.
    [keymap.SchDoc, keymap144.SchDoc]
2016-11-07 Continue routing. Change voltage supply for led driver chip.
    [cpu.SchDoc, keymap.SchDoc, led.SchDoc]
2016-11-07 Continue routing. Add possibility to choose serial signal for ftdi. Connect SO fifo output to unused pin.
    [connectors.SchDoc, cpu.SchDoc]
2016-11-07 Complete CPU routing.
    [connectors.SchDoc]
2016-11-07 Complete all routing.
    [Connectors.SchDoc, connectors.SchDoc]
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2016-11-07 Add planes.
    [connectors.SchDoc, cpu.SchDoc, petroskey.PrjPcb]
2016-11-07 Fix planes. Add stiching.
    [petroskey.PrjPcb]
2016-11-07 Fix silk screen fix various errors. Complete pcb routing.
2016-11-07 Fix schematics for ink display. Add board outline for display.
    [connectors.SchDoc, display.PcbDoc, display.PrjPcb]
2016-11-07 Complete scheme for display adapter.
    [connectors.SchDoc, display.PcbDoc]
2016-11-07 Update scheme anche make clean-up of prj.
    [connectors.SchDoc, controller.PrjPcb, cpu.SchDoc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]
2016-11-07 Use only test point for key and leds. Update pcb.
    [connectors.SchDoc, controller.PcbDoc, controller.PrjPcb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]
2016-11-07 Fix silk screen. Start to place controller pcb.
    [controller.PcbDoc]
2016-11-07 Add configuration for display.
    [connectors.SchDoc, display.PrjPcb]
2016-11-07 Increase x size of display adaptor board.
    [display.PcbDoc]
2016-11-07 Complete routing.
    [controller.PcbDoc, controller.PrjPcb, cpu.SchDoc]
2016-11-07 Some fix to define outline.
    [connectors.SchDoc, controller.PcbDoc, controller.PrjPcb]
2016-11-07 Complete planes.
    [controller.PcbDoc]
2016-11-07 Fix silk screen.
    [connectors.SchDoc, display.PcbDoc, keymap.SchDoc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]
2016-11-07 Fix planes and minor errors.
    [controller.PrjPcb, display.PcbDoc]
2016-11-07 Generate gerber files.
    [panel.GBL, panel.GBO, panel.GBP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]
2016-11-07 Add pdf and bom files.
    [bom-controller.xlsx, bom-petroskey.xlsx]
2016-11-09 [fw] revert bertos changes
    [clock_stm32.h]
2016-11-09 [fw] fix LED_ON and LED_OFF
2016-11-09 [fw] reworking according to bertos coding style
    [layouts.h, main.c]
2016-11-09 Add new layout
    [pietroskey_layout.dxf]
2016-11-09 Add layout for another version
    [asterix_layout.dxf]
2016-11-09 [fw] enable SIPO driver and LED implementation stub
2016-11-09 [fw] temporarily disable processes and test LEDs using timers
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2016-11-09 Fix misalignment off git status key.
    [asterix_layout.dxf]
2016-11-09 [fw] wait 2us between pin write and read
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2016-11-09 [fw] fix layout sizes
    [layouts.h]
2016-11-09 [fw] tracking 6 keys at once.
    The software now tracks at most 6 keys pressed at once. More than 6 keys
    are ignored, as the usb protocol does not allow to send more. We only
    track the first 6 keys we encounter, and we discard the rest. All
    modifiers are read anyway and correctly set no matter how many keys are
    pressed at once.
    Bertos was modified since its API did not allow sending multiple key
    presses at once.
    [main.c]
2016-11-17 [fw] eeprom: use I2C bitbang driver, fix I2C pins
    [main.c]
2016-11-19 Add drawing for new layout.
    [asterix_layout_variante.dxf]
2017-02-22 Change basic position of esc key and canc.
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2017-02-22 Layout variant.
    [asterix_layout_variante.dwg]
2017-02-22 Rename src directory to contain all board firmware source.
2017-03-19 Refactor code to use unique context. Fix echo with new refactoring.
    [main.c]
2017-04-17 Refactor code. Start to get status from device.
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2017-04-25 Use macro for application address. Enable timer_cleanup before to jump to avoid segmentation fault.
    [main.c]
2017-04-25 Fix to use usbfeature module.
    [main.c]
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2018-09-10 New layout.
    [asterix_layout_variante.dwg, asterix_layout_variante.dxf]
2018-10-01 Add print layout.
    [asterix-print.dxf, asterix_layout_variante.dwg]
2018-10-04 Add controller board light version project.
    [connectors.SchDoc, controller-light.PcbDoc, controller-light.PrjPcb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]
2018-10-05 Continue roting.
    [connectors.SchDoc, controller-light.PcbDoc, cpu.SchDoc]
2018-10-07 Complete routing. Generate gerber files.
    [connectors.SchDoc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]
2018-10-08 Generate output files.
    [bom-controller-light.xlsx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]
2018-10-08 Some fix.
    [controller-light.PrjPcb]
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2018-10-18 Fix pin map for petroskey layout.
2018-10-18 Increse button pressed detect delay to avoid debounce.

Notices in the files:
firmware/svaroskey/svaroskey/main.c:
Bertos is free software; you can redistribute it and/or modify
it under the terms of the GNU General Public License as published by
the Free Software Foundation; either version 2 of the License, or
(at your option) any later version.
